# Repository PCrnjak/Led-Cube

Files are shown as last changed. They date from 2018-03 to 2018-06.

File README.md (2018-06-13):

# **Led-Cube**

34053068_1499386373505176_169624549329993728_n (https://www.youtube.com/watch?v=qzwoztolV-c)

## Intro

Small and compact led cube powered by usb  that is (kinda) easy to build.I decided to make this project for my own amusement and to train smd soldering and pcb design. Code and program are not made  by me all credit goes to: http://www.instructables.com/id/LED-CUBE-CODE-4x4x4-Arduino/ .

## Table of contents
 1. [Intro](#intro)
 2. [Table of contents](#table)
 3. [Bill of materials](#bill)
 4. [Making boards](#board)
 5. [Soldering components](#solder)
 6. [Burning Arduino bootloader](#burn)
 7. [Code](#code)
 8. [Case](#case)

## Bill of materials
  [ Bill of materials](https://github.com/Ropecar5/Led-Cube/blob/master/BILL%20OF%20MATERIALS.txt)
# Making boards
in [GBRLS](https://github.com/Ropecar5/Led-Cube/tree/master/GRBLS) folder there are all grbl files needed to make boards for led cube.
you will need to make 2 boards ,one top one on wich you will place your led cube and one bottom one that has all electronics.
There are also Eagle schematic and board files for both pcbs . I ordered them [JLC pcb](https://jlcpcb.com/) and they came fine.
8253991a-6bf4-496f-b503-892c4d37bfae

# Soldering components
 Well you will need to have some skills with soldering iron and solder all those smd components. Hardest part is soldering leds .You will need to cut 16 3mm holes that are 1.5 mm one from another on peace of cardboard. This will keep all leds at exact distance and make soldering easier.you will need to solder all 4 led planes with magnet wire to pcb board.
 
 # Burning Arduino bootlaoder
 Maybe you can find those smd atmega 328 with already burnt bootloader or you can burn it yourself. I made a mistake on board and didnt want to redo it so to burn bootloader follow these instructions.ledkocka bootloader
 solder wires like shown in picture ,  and connect them to ftdi programmer .
Miso to miso , mosi to mosi , sck to sck , gnd to gnd ,vcc to vcc,DTR ON LED BOARD is not dtr .
Connect dtr from ftdi programmer to wire that is shown on picture.Cap on picture is 47 uF.

# Code
Once again code is not written by me. There are 2 example programs [LEDFADE](https://github.com/Ropecar5/Led-Cube/tree/master/LEDFADE) and
[shooting star](https://github.com/Ropecar5/Led-Cube/tree/master/shooting_star).[LCCG.exe](https://github.com/Ropecar5/Led-Cube/blob/master/LCCG.exe) is program used to generate patterns in wich cube will light up.  To upload code you will need FTDI usb to TTL serial converter that connects to corresponding pins on board.
# Case
[STL](https://github.com/Ropecar5/Led-Cube/tree/master/files) file. Printed on cheap chinese prusa clone with 0.2 mm layer height.

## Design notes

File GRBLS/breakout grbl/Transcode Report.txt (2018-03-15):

   ---- Transcoding 'C:\Users\Rope\Desktop\GRBLS\led kocka gornja.GBS' ----   Sat Feb 03 20:19:41 2018

D10   --> D100
-----------------------------------------------------------------

   ---- Transcoding 'C:\Users\Rope\Desktop\GRBLS\led kocka gornja.GTL' ----   Sat Feb 03 20:19:41 2018

D10   --> D101
D12   --> D102
-----------------------------------------------------------------

   ---- Transcoding 'C:\Users\Rope\Desktop\GRBLS\led kocka gornja.GTO' ----   Sat Feb 03 20:19:41 2018

D10   --> D103
D11   --> D104
-----------------------------------------------------------------

   ---- Transcoding 'C:\Users\Rope\Desktop\GRBLS\led kocka gornja.GTS' ----   Sat Feb 03 20:19:41 2018

D10   --> D105
D11   --> D106
-----------------------------------------------------------------

   ---- Transcoding 'C:\Users\Rope\Desktop\GRBLS\led kocka gornja.GBS' ----   Sat Feb 03 20:20:59 2018

D10   --> D100
-----------------------------------------------------------------

   ---- Transcoding 'C:\Users\Rope\Desktop\GRBLS\led kocka gornja.GTL' ----   Sat Feb 03 20:20:59 2018

D10   --> D101
D12   --> D102
-----------------------------------------------------------------

   ---- Transcoding 'C:\Users\Rope\Desktop\GRBLS\led kocka gornja.GTO' ----   Sat Feb 03 20:20:59 2018

D10   --> D103
D11   --> D104
-----------------------------------------------------------------

   ---- Transcoding 'C:\Users\Rope\Desktop\GRBLS\led kocka gornja.GTS' ----   Sat Feb 03 20:20:59 2018

D10   --> D105
D11   --> D106
-----------------------------------------------------------------

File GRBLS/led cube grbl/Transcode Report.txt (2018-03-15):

   ---- Transcoding 'C:\Users\Rope\Desktop\GRBLS\led cube grbl\led kocka shematic.GBS' ----   Sat Feb 03 21:56:21 2018

D10   --> D100
D11   --> D101
D12   --> D102
D13   --> D103
D14   --> D104
D15   --> D105
-----------------------------------------------------------------

   ---- Transcoding 'C:\Users\Rope\Desktop\GRBLS\led cube grbl\led kocka shematic.GTL' ----   Sat Feb 03 21:56:21 2018

D10   --> D106
D11   --> D107
D12   --> D108
D13   --> D109
D14   --> D110
D15   --> D111
-----------------------------------------------------------------

   ---- Transcoding 'C:\Users\Rope\Desktop\GRBLS\led cube grbl\led kocka shematic.GTO' ----   Sat Feb 03 21:56:21 2018

D10   --> D112
D11   --> D113
D12   --> D114
D13   --> D115
D14   --> D116
D15   --> D117
D16   --> D118
D17   --> D119
-----------------------------------------------------------------

   ---- Transcoding 'C:\Users\Rope\Desktop\GRBLS\led cube grbl\led kocka shematic.GTS' ----   Sat Feb 03 21:56:21 2018

D10   --> D120
D11   --> D121
D12   --> D122
D13   --> D123
D14   --> D124
D15   --> D125
D16   --> D126
D17   --> D127
D18   --> D128
D19   --> D129
D20   --> D130
D21   --> D131
D22   --> D132
D23   --> D133
D24   --> D134
D25   --> D135
D26   --> D136
D27   --> D137
-----------------------------------------------------------------

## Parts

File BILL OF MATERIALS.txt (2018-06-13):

///////////////////////////////////////
BILL OF MATERIALS /////////////////////
///////////////////////////////////////

RESISTORS:
17 x 0805 package 330 ohm 
1  x 0805 package 10 Kohm 
4  x 0805 package 540 ohm

CAPACITORS:
3  x 0805 package 0.1 uF 
2  x 0805 package 22 pF

LED DIODES:
64 x 3mm White led
1 x 0603 Red led

_______________________
1 x Atmega328p -TQFP
1 x HC49UP package 16 Mhz crystal oscillator
1 x SMD usb mini B 5 pin
1 x  3X6X2.5mm Tactile Push Button SMD
4 x MMBT2222 SOT-23 2N2222 SMD NPN Transistor 
-Female and male header pins ( few rows )
-Magnet wire

//////////////////////////////////////////

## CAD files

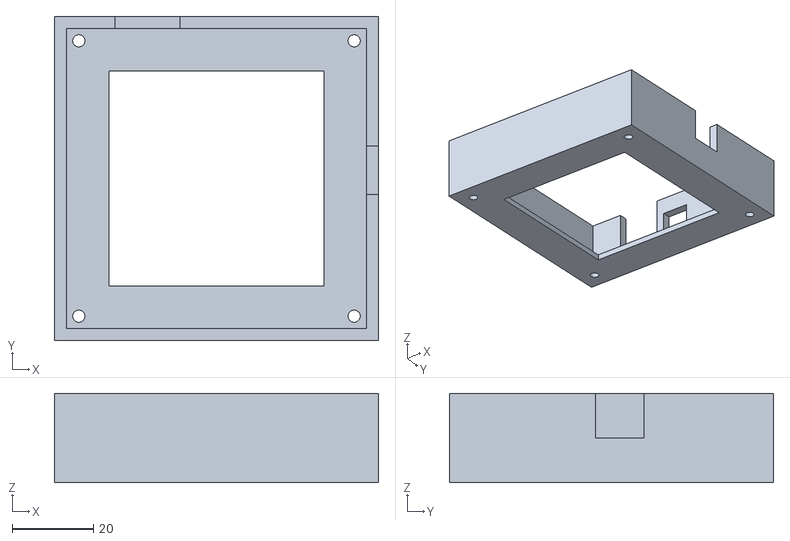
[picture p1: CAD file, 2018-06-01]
files/case_3.0.STL
80.0 x 80.0 x 22.0

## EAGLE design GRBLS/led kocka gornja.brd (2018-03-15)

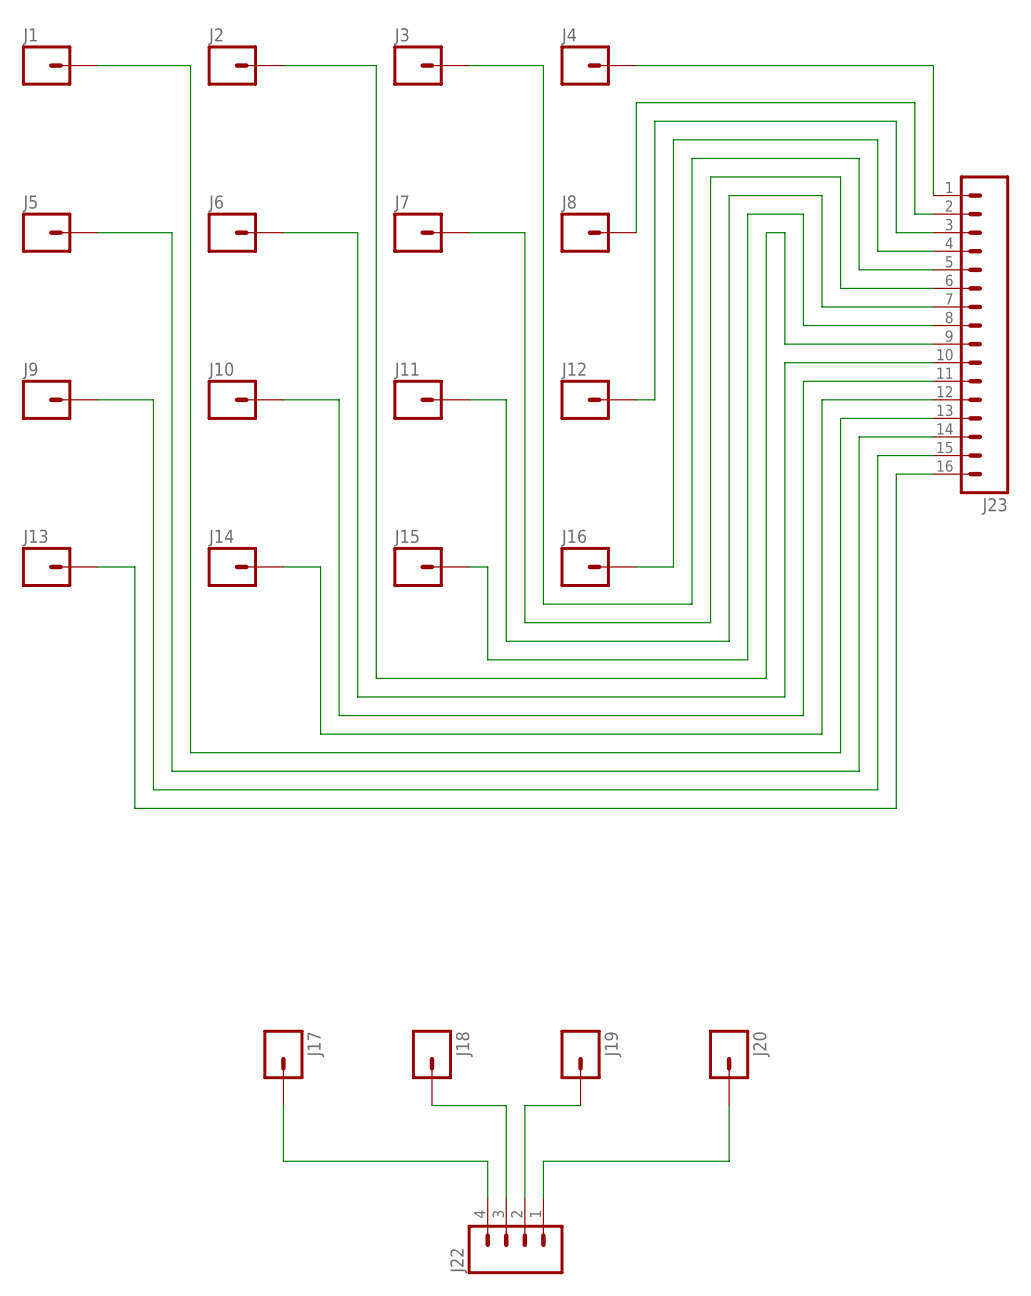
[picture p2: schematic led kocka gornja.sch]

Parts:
J1, J2, J3, J4, J5, J6, J7, J8, J9, J10, J11, J12, J13, J14, J15, J16, J17, J18, J19, J20: M01NOSILK-KIT; 1X01NS-KIT
J22: M04LONGPADS; 1X04_LONGPADS
J23: M16LONGPADS; 1X16_LONGPADS

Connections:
unnamed: J4.1, J23.1
unnamed: J8.1, J23.2
unnamed: J12.1, J23.3
unnamed: J16.1, J23.4
unnamed: J3.1, J23.5
unnamed: J7.1, J23.6
unnamed: J11.1, J23.7
unnamed: J15.1, J23.8
unnamed: J2.1, J23.9
unnamed: J6.1, J23.10
unnamed: J14.1, J23.12
unnamed: J1.1, J23.13
unnamed: J10.1, J23.11
unnamed: J5.1, J23.14
unnamed: J9.1, J23.15
unnamed: J13.1, J23.16
unnamed: J17.1, J22.4
unnamed: J20.1, J22.1
unnamed: J18.1, J22.3
unnamed: J19.1, J22.2

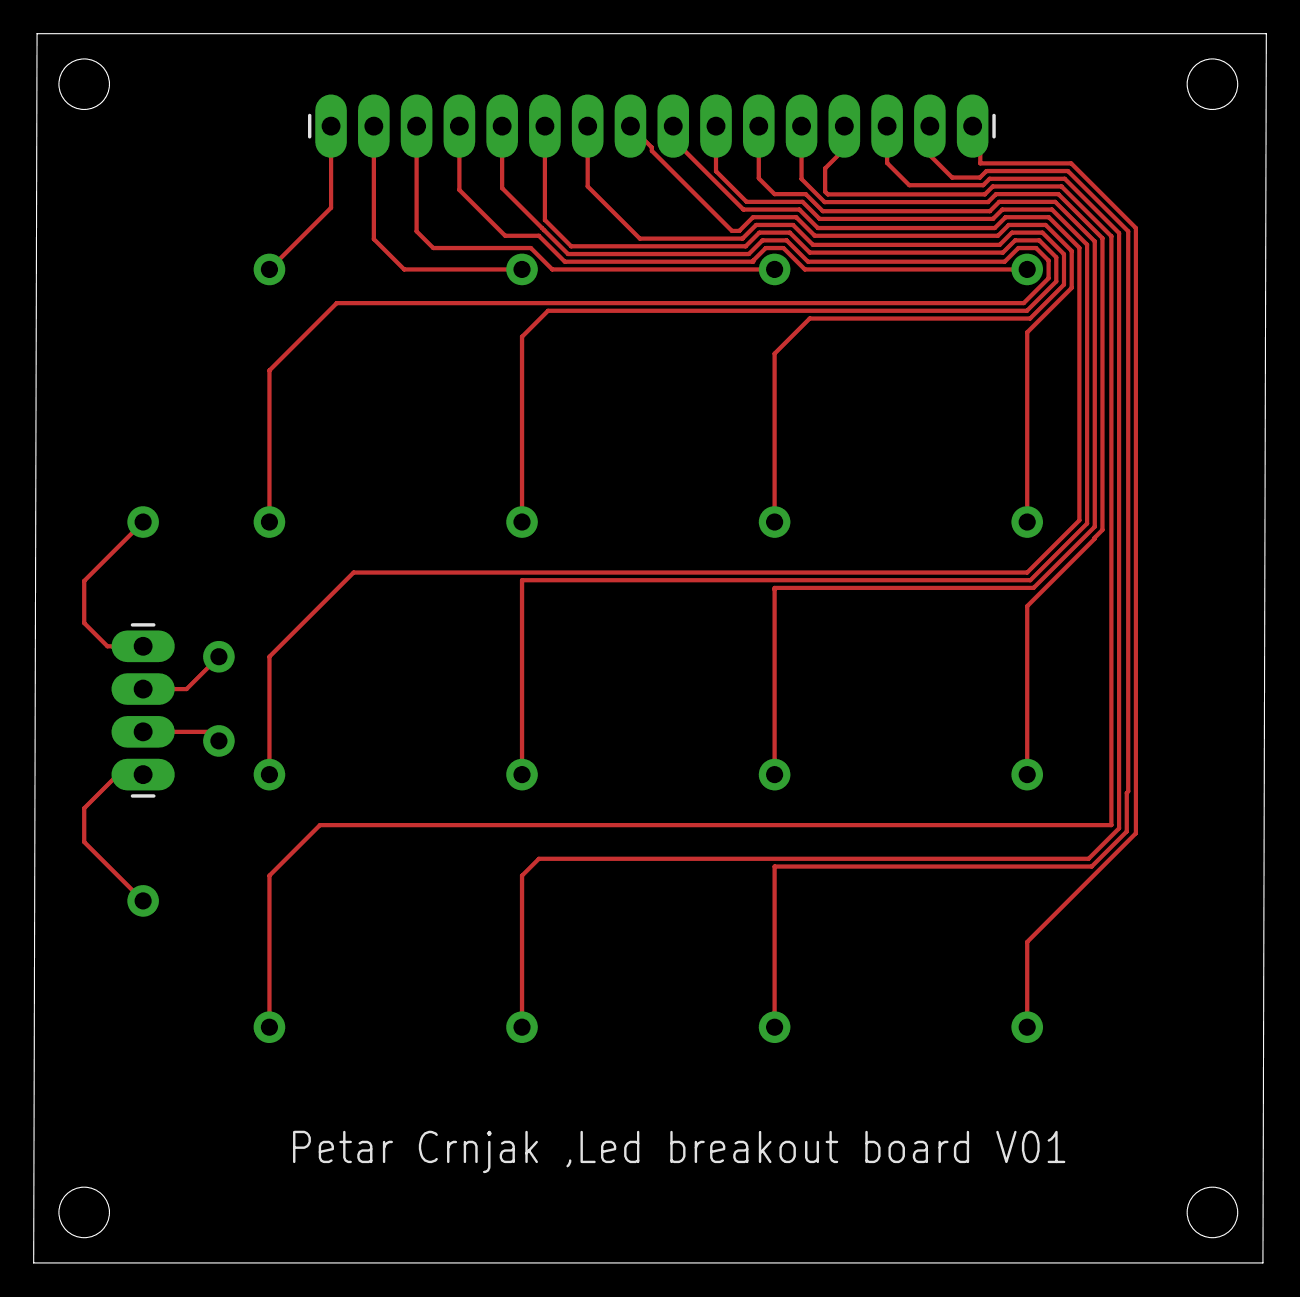
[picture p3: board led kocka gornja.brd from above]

Board: 2 copper layers, 73.2 x 73.0 mm, 22 parts (0 on the bottom side), 20 nets.

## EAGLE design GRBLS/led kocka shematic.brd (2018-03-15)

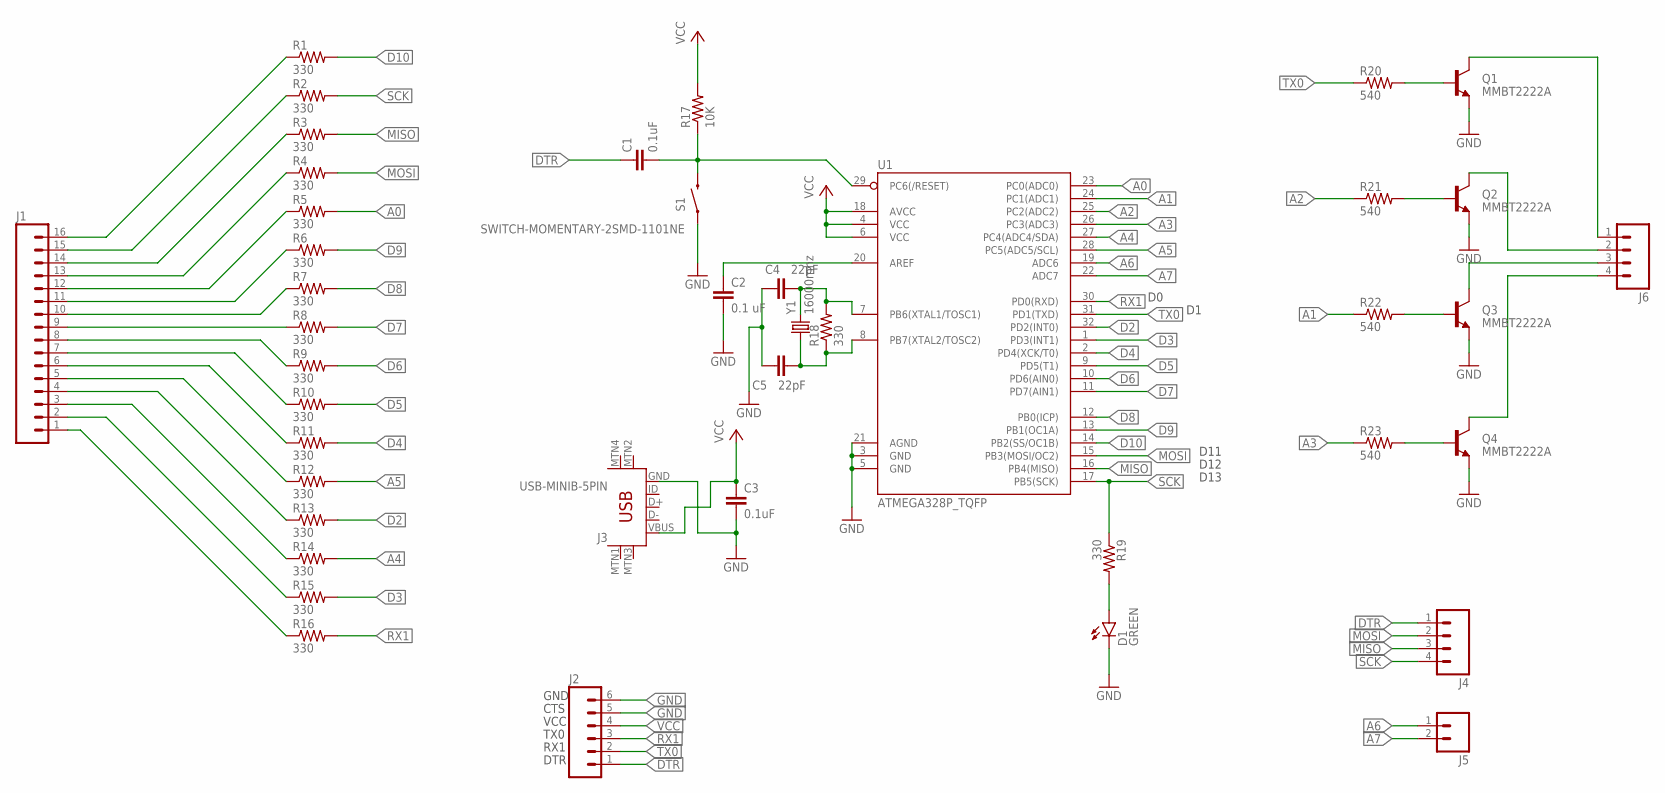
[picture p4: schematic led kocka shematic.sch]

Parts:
C1, C3: 0.1uF; 0805-CAP
C2: 0.1 uF; 0805-CAP
C4, C5: 22pF; 0805-CAP
D1: GREEN; LED-0603
J1: M16LONGPADS; 1X16_LONGPADS
J2: M06LONGPADS; 1X06_LONGPADS
J3: USB-MINIB-5PIN; USB-MINIB
J4, J6: M04LONGPADS; 1X04_LONGPADS
J5: M02LOCK_LONGPADS; 1X02_LOCK_LONGPADS
Q1, Q2, Q3, Q4: MMBT2222A; SOT23-3
R1, R2, R3, R4, R5, R6, R7, R8, R9, R10, R11, R12, R13, R14, R15, R16, R18, R19: 330; R0805
R17: 10K; R0805
R20, R21, R22, R23: 540; R0805
S1: SWITCH-MOMENTARY-2SMD-1101NE; TACTILE-SWITCH-1101NE
U1: ATMEGA328P_TQFP; TQFP32-08
Y1: 16000mhz; HC49UP

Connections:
A0: R5.2, U1.23 (PC0(ADC0))
A1: R22.1, U1.24 (PC1(ADC1))
A2: R21.1, U1.25 (PC2(ADC2))
A3: R23.1, U1.26 (PC3(ADC3))
A4: R14.2, U1.27 (PC4(ADC4/SDA))
A5: R12.2, U1.28 (PC5(ADC5/SCL))
A6: J5.1, U1.19 (ADC6)
A7: J5.2, U1.22 (ADC7)
D2: R13.2, U1.32 (PD2(INT0))
D3: R15.2, U1.1 (PD3(INT1))
D4: R11.2, U1.2 (PD4(XCK/T0))
D5: R10.2, U1.9 (PD5(T1))
D6: R9.2, U1.10 (PD6(AIN0))
D7: R8.2, U1.11 (PD7(AIN1))
D8: R7.2, U1.12 (PB0(ICP))
D9: R6.2, U1.13 (PB1(OC1A))
D10: R1.2, U1.14 (PB2(SS/OC1B))
DTR: C1.1, J2.1, J4.1
GND: C2.2, C3.2, C4.1, C5.1, D1.C, J2.5, J2.6, J3.GND, Q1.2 (E), Q2.2 (E), Q3.2 (E), Q4.2 (E), S1.1, U1.3 (GND), U1.5 (GND), U1.21 (AGND)
MISO: J4.3, R3.2, U1.16 (PB4(MISO))
MOSI: J4.2, R4.2, U1.15 (PB3(MOSI/OC2))
unnamed: C4.2, R18.2, U1.7 (PB6(XTAL1/TOSC1)), Y1.2
unnamed: J1.16, R1.1
unnamed: C1.2, R17.1, S1.2, U1.29 (PC6(/RESET))
unnamed: C5.2, R18.1, U1.8 (PB7(XTAL2/TOSC2)), Y1.1
unnamed: C2.1, U1.20 (AREF)
unnamed: J1.15, R2.1
unnamed: J1.14, R3.1
unnamed: J1.13, R4.1
unnamed: J1.12, R5.1
unnamed: J1.11, R6.1
unnamed: D1.A, R19.2
unnamed: J1.1, R16.1
unnamed: J1.2, R15.1
unnamed: J1.3, R14.1
unnamed: J1.4, R13.1
unnamed: J1.5, R12.1
unnamed: J1.6, R11.1
unnamed: J1.7, R10.1
unnamed: J1.8, R9.1
unnamed: J1.9, R8.1
unnamed: J1.10, R7.1
unnamed: Q1.1 (B), R20.2
unnamed: Q2.1 (B), R21.2
unnamed: Q3.1 (B), R22.2
unnamed: Q4.1 (B), R23.2
unnamed: J6.1, Q1.3 (C)
unnamed: J6.2, Q2.3 (C)
unnamed: J6.3, Q3.3 (C)
unnamed: J6.4, Q4.3 (C)
RX1: J2.3, R16.2, U1.30 (PD0(RXD))
SCK: J4.4, R2.2, R19.1, U1.17 (PB5(SCK))
TX0: J2.2, R20.1, U1.31 (PD1(TXD))
VCC: C3.1, J2.4, J3.VBUS, R17.2, U1.4 (VCC), U1.6 (VCC), U1.18 (AVCC)

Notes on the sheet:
GND
CTS
VCC
TX0
RX1
DTR
D13
D12
D11

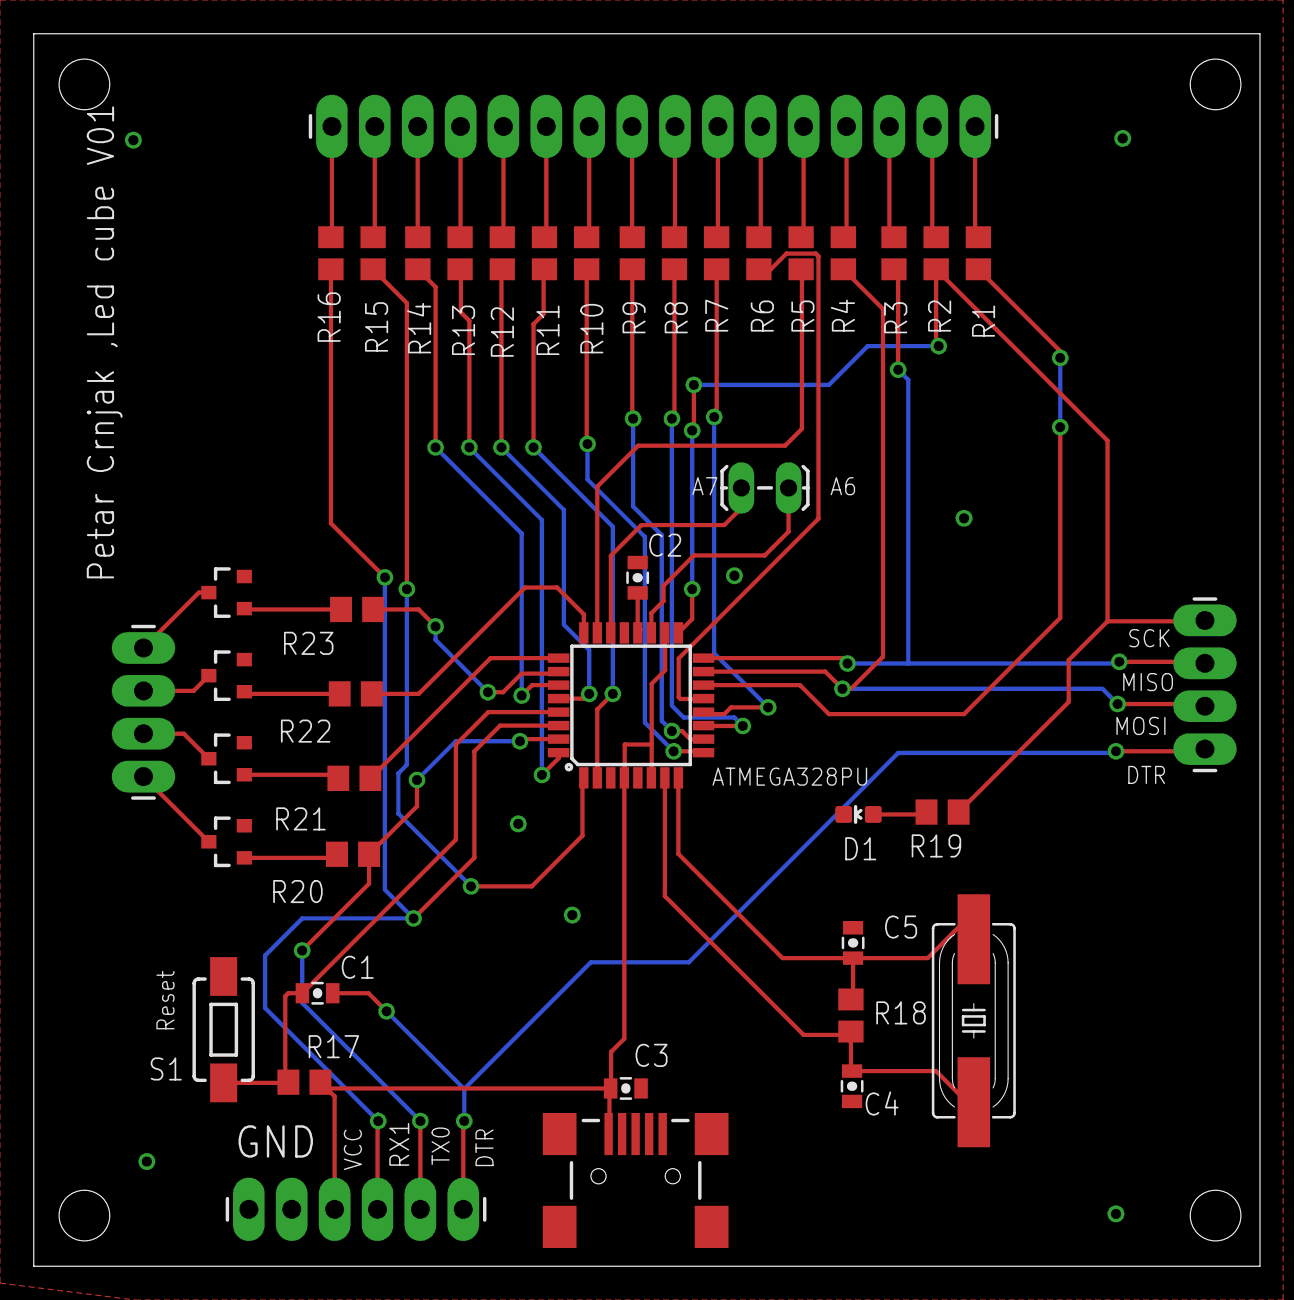
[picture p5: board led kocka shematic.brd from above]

Board: 2 copper layers, 72.6 x 73.0 mm, 42 parts (0 on the bottom side), 54 nets.

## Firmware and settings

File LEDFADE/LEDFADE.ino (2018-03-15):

//4x4x4 LED Cube Show 1
//This one was written by someone else, i dont know who, however if you want credit, message me!

#include <avr/pgmspace.h> // allows use of PROGMEM to store patterns in flash

#define CUBESIZE 4
#define PLANESIZE CUBESIZE*CUBESIZE
#define PLANETIME 2000 // time each plane is displayed in us -> 100 Hz refresh
#define TIMECONST 10// multiplies DisplayTime to get ms - why not =100?

// LED Pattern Table in PROGMEM - last column is display time in 100ms units
// TODO this could be a lot more compact but not with binary pattern representation
const unsigned char PROGMEM PatternTable[] = {
// blink on and off
//Floor:
//1            1         1          1           2          2          2           2           3         3           3          3          4           4          4          4  
//Row:
//1            2         3          4           1          2          3           4           1         2           3          4           1          2          3          4
B0000,B0000,B0000,B1111   ,B0000,B0000,B0000,B1111   ,B0000,B0000,B0000,B1111   ,B0000,B0000,B0000,B1111   , 8,
B0000,B0000,B1111,B1111   ,B0000,B0000,B1111,B1111   ,B0000,B0000,B1111,B1111   ,B0000,B0000,B1111,B1111   , 8,
B0000,B1111,B1111,B1111   ,B0000,B1111,B1111,B1111   ,B0000,B1111,B1111,B1111   ,B0000,B1111,B1111,B1111   , 8,
B1111,B1111,B1111,B1111   ,B1111,B1111,B1111,B1111   ,B1111,B1111,B1111,B1111   ,B1111,B1111,B1111,B1111   , 8,
B1111,B1111,B1111,B0000   ,B1111,B1111,B1111,B0000   ,B1111,B1111,B1111,B0000   ,B1111,B1111,B1111,B0000   , 8,
B1111,B1111,B0000,B0000   ,B1111,B1111,B0000,B0000   ,B1111,B1111,B0000,B0000   ,B1111,B1111,B0000,B0000   , 8,
B1111,B0000,B0000,B0000   ,B1111,B0000,B0000,B0000   ,B1111,B0000,B0000,B0000   ,B1111,B0000,B0000,B0000   , 8,
B0000,B0000,B0000,B0000   ,B0000,B0000,B0000,B0000   ,B0000,B0000,B0000,B0000   ,B0000,B0000,B0000,B0000   , 8,

B0000,B0000,B0000,B1111   ,B0000,B0000,B0000,B1111   ,B0000,B0000,B0000,B1111   ,B0000,B0000,B0000,B1111   , 8,
B0000,B0000,B1111,B1111   ,B0000,B0000,B1111,B1111   ,B0000,B0000,B1111,B1111   ,B0000,B0000,B1111,B1111   , 8,
B0000,B1111,B1111,B1111   ,B0000,B1111,B1111,B1111   ,B0000,B1111,B1111,B1111   ,B0000,B1111,B1111,B1111   , 8,
B1111,B1111,B1111,B1111   ,B1111,B1111,B1111,B1111   ,B1111,B1111,B1111,B1111   ,B1111,B1111,B1111,B1111   , 8,
B1111,B1111,B1111,B0000   ,B1111,B1111,B1111,B0000   ,B1111,B1111,B1111,B0000   ,B1111,B1111,B1111,B0000   , 8,
B1111,B1111,B0000,B0000   ,B1111,B1111,B0000,B0000   ,B1111,B1111,B0000,B0000   ,B1111,B1111,B0000,B0000   , 8,
B1111,B0000,B0000,B0000   ,B1111,B0000,B0000,B0000   ,B1111,B0000,B0000,B0000   ,B1111,B0000,B0000,B0000   , 8,
B0000,B0000,B0000,B0000   ,B0000,B0000,B0000,B0000   ,B0000,B0000,B0000,B0000   ,B0000,B0000,B0000,B0000   , 8,

B1111,B1111,B1111,B1111   ,B0000,B0000,B0000,B0000   ,B0000,B0000,B0000,B0000   ,B0000,B0000,B0000,B0000   , 8,
B1111,B1111,B1111,B1111   ,B1111,B1111,B1111,B1111   ,B0000,B0000,B0000,B0000   ,B0000,B0000,B0000,B0000   , 8,
B1111,B1111,B1111,B1111   ,B1111,B1111,B1111,B1111   ,B1111,B1111,B1111,B1111   ,B0000,B0000,B0000,B0000   , 8,
B1111,B1111,B1111,B1111   ,B1111,B1111,B1111,B1111   ,B1111,B1111,B1111,B1111   ,B1111,B1111,B1111,B1111   , 8,
B0000,B0000,B0000,B0000   ,B1111,B1111,B1111,B1111   ,B1111,B1111,B1111,B1111   ,B1111,B1111,B1111,B1111   , 8,
B0000,B0000,B0000,B0000   ,B0000,B0000,B0000,B0000   ,B1111,B1111,B1111,B1111   ,B1111,B1111,B1111,B1111   , 8,
B0000,B0000,B0000,B0000   ,B0000,B0000,B0000,B0000   ,B0000,B0000,B0000,B0000   ,B1111,B1111,B1111,B1111   , 8,
B0000,B0000,B0000,B0000   ,B0000,B0000,B0000,B0000   ,B0000,B0000,B0000,B0000   ,B0000,B0000,B0000,B0000   , 8,

B1111,B1111,B1111,B1111   ,B0000,B0000,B0000,B0000   ,B0000,B0000,B0000,B0000   ,B0000,B0000,B0000,B0000   , 8,
B1111,B1111,B1111,B1111   ,B1111,B1111,B1111,B1111   ,B0000,B0000,B0000,B0000   ,B0000,B0000,B0000,B0000   , 8,
B1111,B1111,B1111,B1111   ,B1111,B1111,B1111,B1111   ,B1111,B1111,B1111,B1111   ,B0000,B0000,B0000,B0000   , 8,
B1111,B1111,B1111,B1111   ,B1111,B1111,B1111,B1111   ,B1111,B1111,B1111,B1111   ,B1111,B1111,B1111,B1111   , 8,
B0000,B0000,B0000,B0000   ,B1111,B1111,B1111,B1111   ,B1111,B1111,B1111,B1111   ,B1111,B1111,B1111,B1111   , 8,
B0000,B0000,B0000,B0000   ,B0000,B0000,B0000,B0000   ,B1111,B1111,B1111,B1111   ,B1111,B1111,B1111,B1111   , 8,
B0000,B0000,B0000,B0000   ,B0000,B0000,B0000,B0000   ,B0000,B0000,B0000,B0000   ,B1111,B1111,B1111,B1111   , 8,
B0000,B0000,B0000,B0000   ,B0000,B0000,B0000,B0000   ,B0000,B0000,B0000,B0000   ,B0000,B0000,B0000,B0000   , 8,
// this is a dummy element for end of table (duration=0) aka !!!DO NOT TOUCH!!!
B0000, B0000, B0000, B0000, B0000, B0000, B0000, B0000, B0000, B0000, B0000, B0000, B0000, B0000, B0000, B0000, 0
};

/*
** Defining pins in array makes it easier to rearrange how cube is wired
** Adjust numbers here until LEDs flash in order - L to R, T to B
** Note that analog inputs 0-5 are also digital outputs 14-19!
** Pin DigitalOut0 (serial RX) and AnalogIn5 are left open for future apps
*/




int LEDPin[] = {10, 13, 12, 11, A0, 9, 8, 7, 6, 5, 4, A5, 2, A4, 3, 0};
int PlanePin[] = {1, A2, A1, A3}; 





// initialization
void setup()
{
int pin; // loop counter
// set up LED pins as output (active HIGH)
for (pin=0; pin<PLANESIZE; pin++) {
pinMode( LEDPin[pin], OUTPUT );
}
// set up plane pins as outputs (active LOW)
for (pin=0; pin<CUBESIZE; pin++) {
pinMode( PlanePin[pin], OUTPUT );
}
}

// display pattern in table until DisplayTime is zero (then repeat)
void loop()
{
// declare variables
byte PatternBuf[PLANESIZE]; // saves current pattern from PatternTable
int PatternIdx;
byte DisplayTime; // time*100ms to display pattern
unsigned long EndTime;
int plane; // loop counter for cube refresh
int patbufidx; // indexes which byte from pattern buffer
int ledrow; // counts LEDs in refresh loop
int ledcol; // counts LEDs in refresh loop
int ledpin; // counts LEDs in refresh loop

// Initialize PatternIdx to beginning of pattern table
PatternIdx = 0;
// loop over entries in pattern table - while DisplayTime>0
do {
// read pattern from PROGMEM and save in array
memcpy_P( PatternBuf, PatternTable+PatternIdx, PLANESIZE );
PatternIdx += PLANESIZE;
// read DisplayTime from PROGMEM and increment index
DisplayTime = pgm_read_byte_near( PatternTable + PatternIdx++ );
// compute EndTime from current time (ms) and DisplayTime
EndTime = millis() + ((unsigned long) DisplayTime) * TIMECONST;

// loop while DisplayTime>0 and current time < EndTime
while ( millis() < EndTime ) {
patbufidx = 0; // reset index counter to beginning of buffer
// loop over planes
for (plane=0; plane<CUBESIZE; plane++) {
// turn previous plane off
if (plane==0) {
digitalWrite( PlanePin[CUBESIZE-1], LOW );
} else {
digitalWrite( PlanePin[plane-1], LOW );
}

// load current plane pattern data into ports
ledpin = 0;
for (ledrow=0; ledrow<CUBESIZE; ledrow++) {
for (ledcol=0; ledcol<CUBESIZE; ledcol++) {
digitalWrite( LEDPin[ledpin++], PatternBuf[patbufidx] & (1 << ledcol) );
}
patbufidx++;
}

// turn current plane on
digitalWrite( PlanePin[plane], HIGH );
// delay PLANETIME us
delayMicroseconds( PLANETIME );
} // for plane
} // while <EndTime
} while (DisplayTime > 0); // read patterns until time=0 which signals end
}

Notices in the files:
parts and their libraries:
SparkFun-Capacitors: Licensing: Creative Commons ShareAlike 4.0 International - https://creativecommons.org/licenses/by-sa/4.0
